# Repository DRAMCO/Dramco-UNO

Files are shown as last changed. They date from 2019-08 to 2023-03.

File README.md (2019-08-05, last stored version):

# Dramco UNO

LoRaWAN-enabled Arduino board developed by [DRAMCO](https://www.dramco.be) featuring an accelerometer and a onewire connection optimized for low-power.

## Folder Structure

```
├───app
│   ├───Accelero-Test
│   ├───Dramco-UNO
│   └───Temprature-Sensor-Test
├───hardware
└───libraries
    └───arduino-lmic-master
```

- Example applications can be found in `app`
- Hardware folder includes the schematics 
- Altered libraries can be found in the `libraries`folder

## Description

- The device sends temperature, accelerometer and the battery level each MEASURE_INTERVAL.
- The (onewire) temperature sensor needs to be connected to the TEMP_BUS pin
- The (I2C) accelerometer with id ACC_ID is accessed through the Wire.h library
- The battery level is measured through the readVcc() function
- The measurements sent by the node are formatted with the Cayenne Low Power Payload (https://github.com/myDevicesIoT/cayenne-docs/blob/master/docs/LORA.md)

##  Dependencies:
- OneWire lib
- DallasTemperature lib
- Install arduino-lmic-master in lib folder of the Arduino IDE (for windows this is most likely here: C:\Program Files (x86)\Arduino\libraries)
    * If you do not use the lib provided in this repo, be sure to uncomment '#define DISABLE_JOIN' in src>lmic>config.h
- DeepSleepScheduler lib

- LoRaWAN keys see: https://www.thethingsnetwork.org/docs/devices/registration.html

## How to cite
```LaTex
@Misc{Dramco-UNO,
  author =   {B. Thoen and G. Leenders},
  title =    {{Dramco UNO}},
  howpublished  = "\url{https://github.com/DRAMCO/Dramco-UNO}",
  doi = {10.5281/zenodo.2476999}
}
```

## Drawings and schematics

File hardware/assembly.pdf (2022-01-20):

## DRAMCO UNO

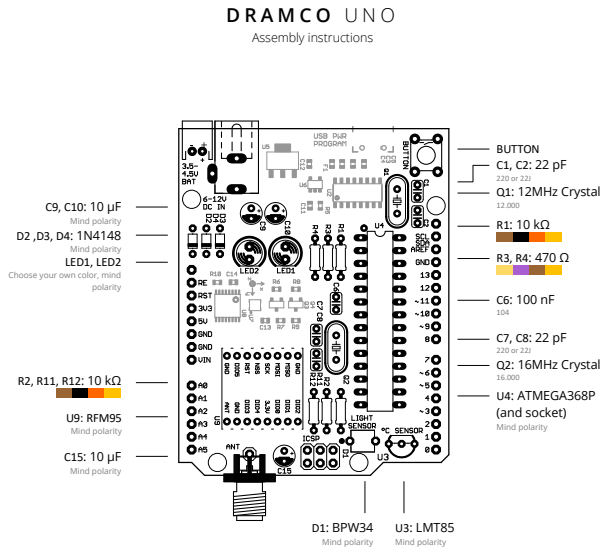
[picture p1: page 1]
Assembly instructions; BUTTON C1, C2: 22 pF 220 or 22J; Q1: 12MHz Crystal 12.000; U4: ATMEGA368P (and socket); Mind polarity; Mind polarity D2 ,D3, D4: 1N4148; Mind polarity LED1, LED2; polarity; Q2: 16MHz Crystal 16.000 R2, R11, R12: 10 kΩ; U3: LMT85; D1: BPW34; U9: RFM95 Mind polarity

Choose your own color, mind

## DRAMCO UNO

Bill of materials (and checklist)

¡ | R1, R2, R11, R12 | Resistors | 10 kΩ
¡ | R3, R4 | Resistors | 470 Ω
¡ | Q1 | Crystal oscillator | 12 MHz
¡ | Q2 | Cyrstal oscillator | 16 MHz
¡ | D1 | Light sensor diode BPW34
¡ | U9 | LoRa module | RFM95
¡ | D2, D3, D4 | Diodes | 1N4148
¡ | C1, C2, C7, C8 | Capacitors | 22 pF
¡ | C6 | Capacitor | 100 nF
¡ | C9, C10, C15 | Capacitors | 10 μF
¡ | LED1, LED2 | LED Diode | 5 mm (choose your own color)
¡ | U3 | Temperature sensor | LMT85
¡ | U4 | IC socket | 28 pin; for ATMEGA328P
¡ | BUTTON | Button | Push button
¡ | ANT | Antenna | Wire antenna 8.2 cm
0 | 1 | 2 | 3 | 4 | 5 | 6 | 7 | 8 | 9 | 10 | 11

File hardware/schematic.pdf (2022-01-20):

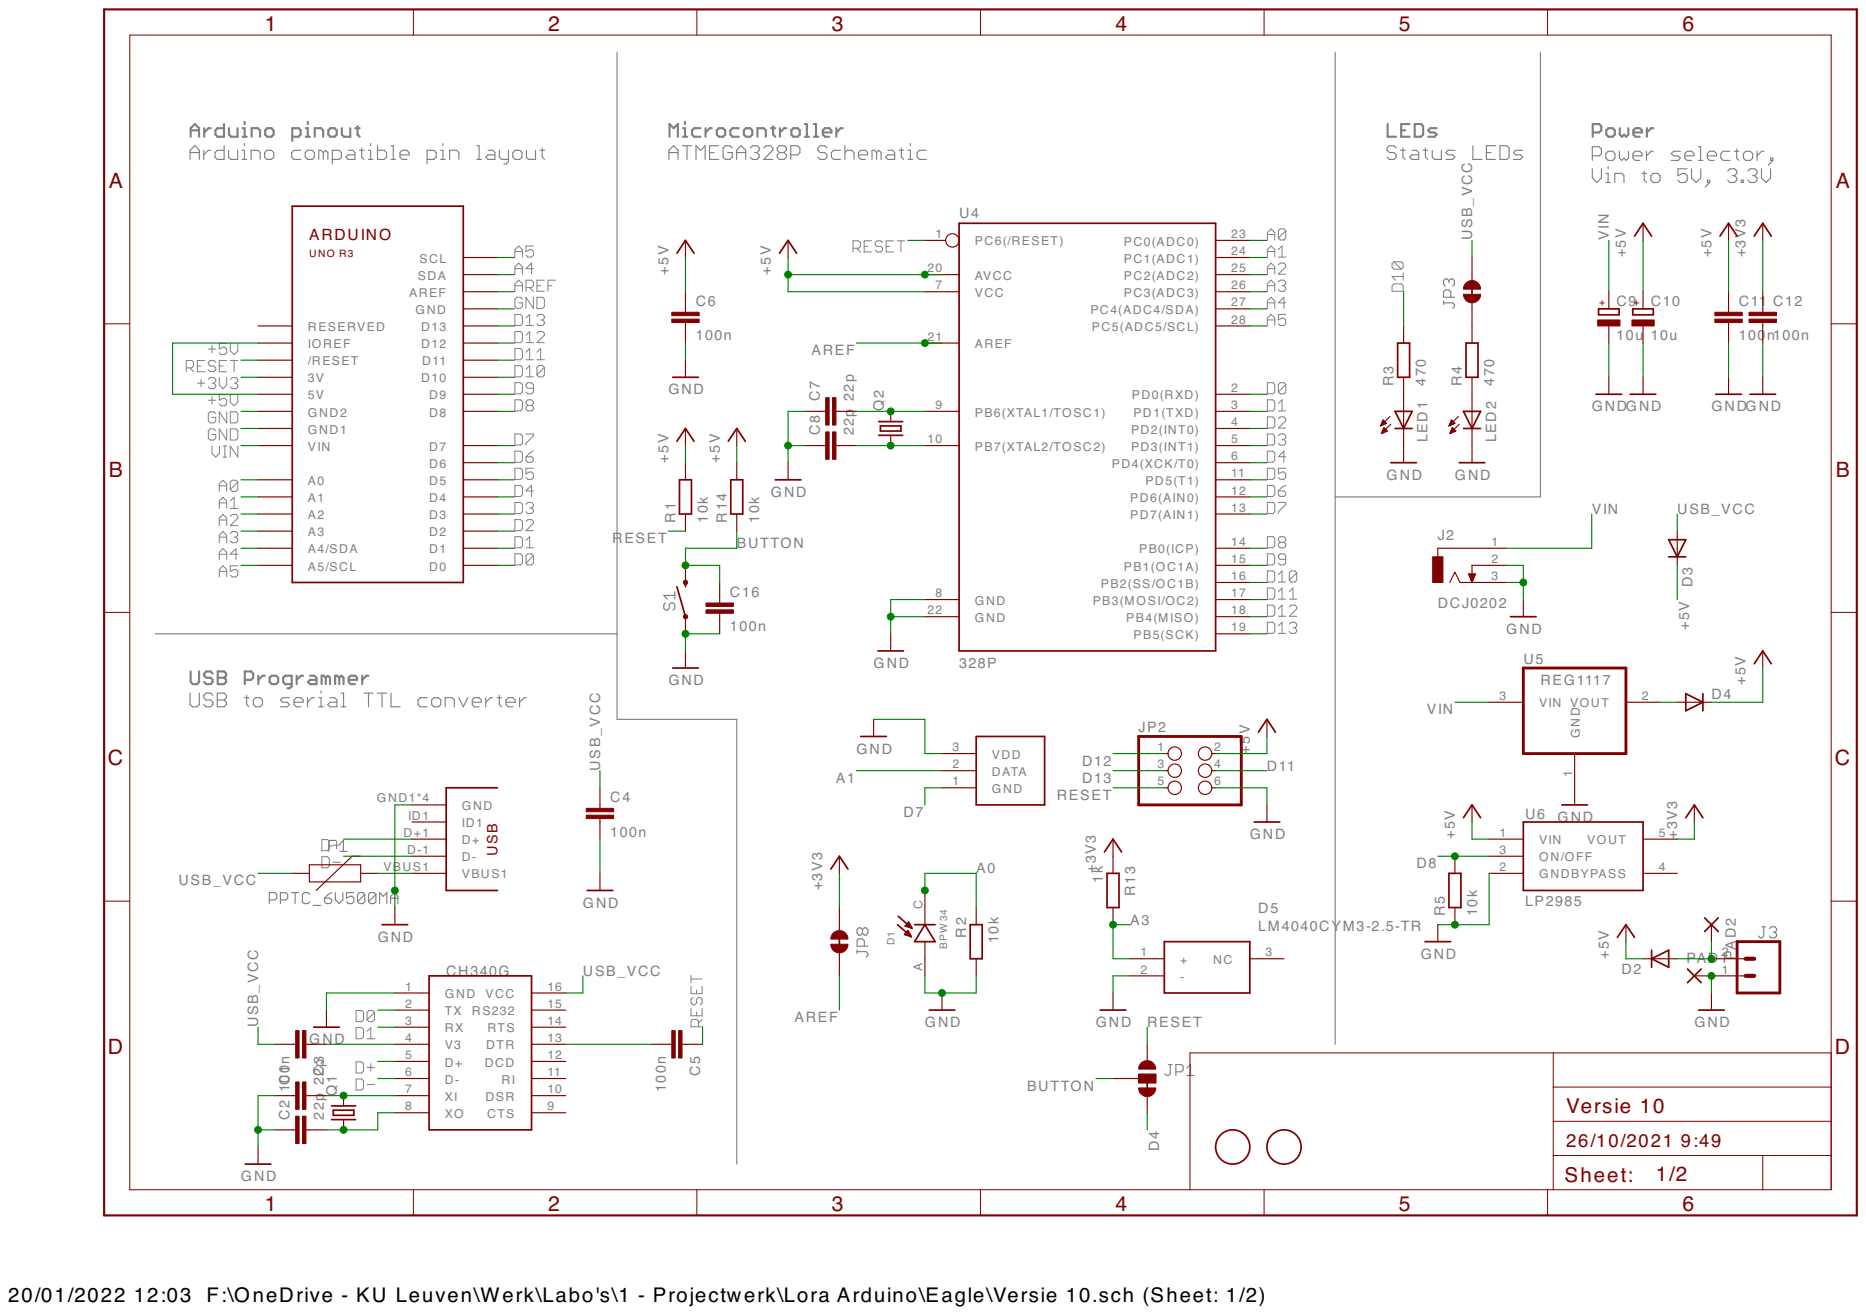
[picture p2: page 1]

20/01/2022 12:03 F:\OneDrive - KU Leuven\Werk\Labo's\1 - Projectwerk\Lora Arduino\Eagle\Versie 10.sch (Sheet: 1/2)

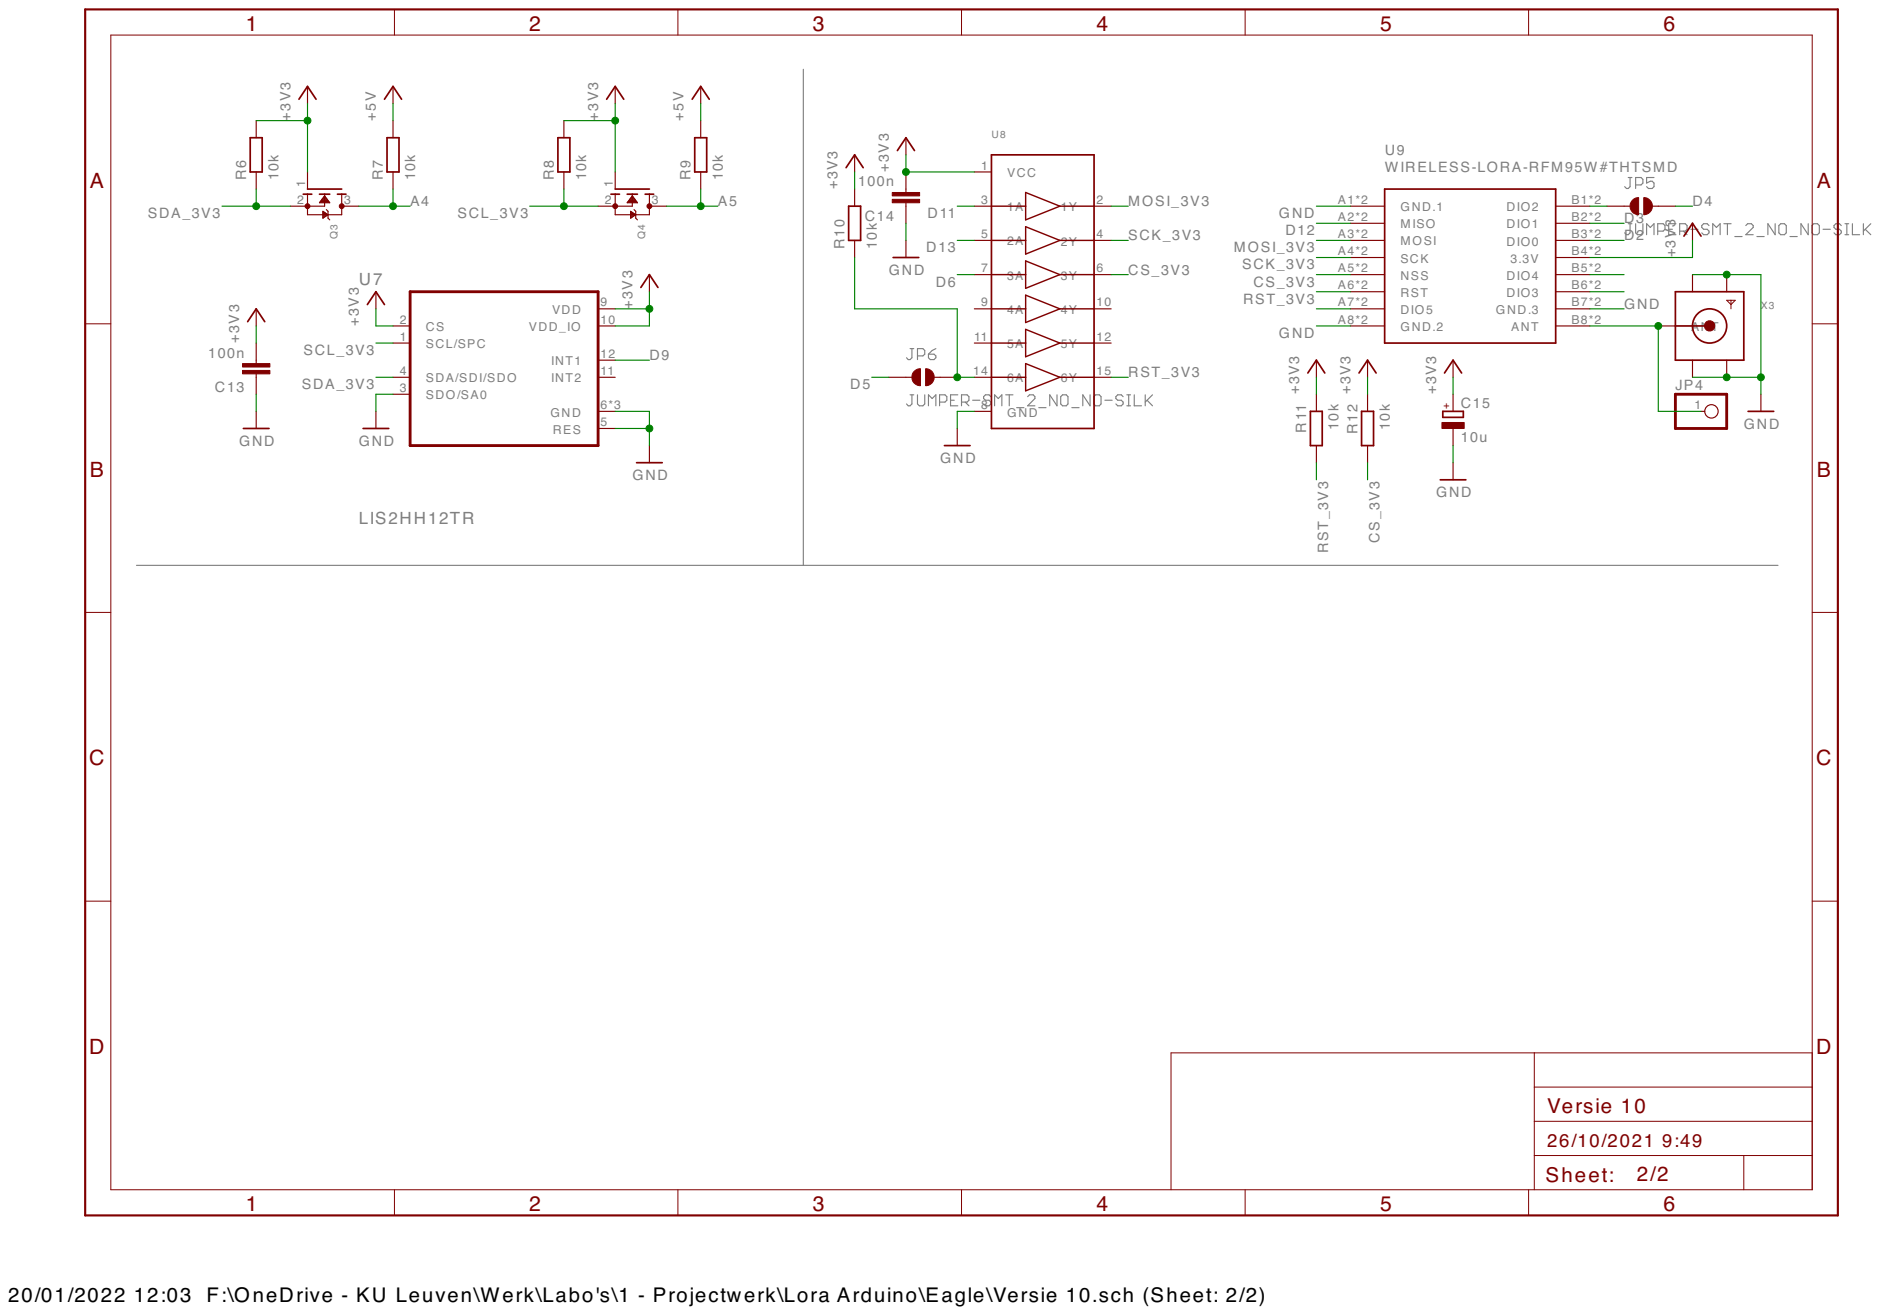
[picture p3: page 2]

20/01/2022 12:03 F:\OneDrive - KU Leuven\Werk\Labo's\1 - Projectwerk\Lora Arduino\Eagle\Versie 10.sch (Sheet: 2/2)

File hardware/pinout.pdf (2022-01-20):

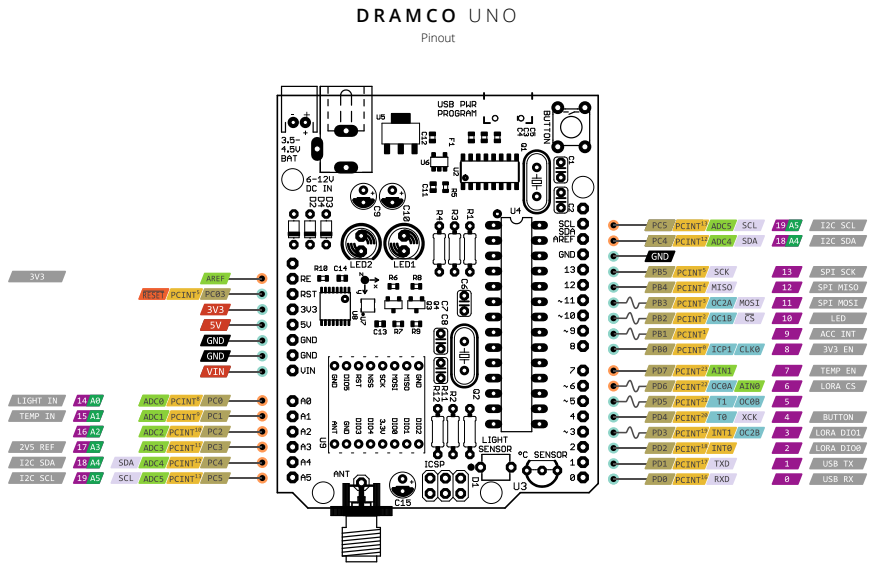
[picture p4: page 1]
Pinout

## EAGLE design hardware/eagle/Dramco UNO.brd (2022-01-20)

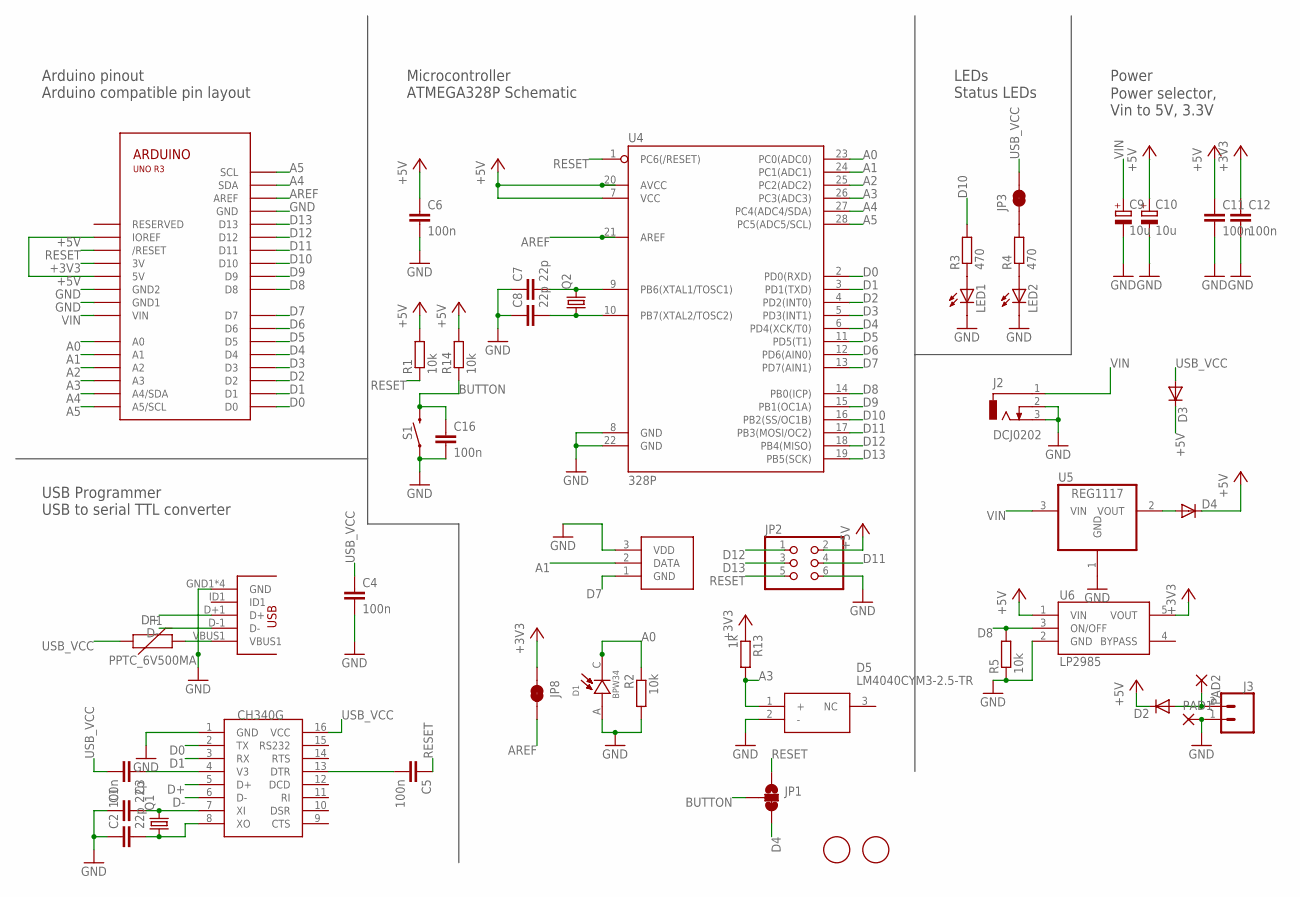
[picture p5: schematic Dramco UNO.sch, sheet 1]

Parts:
C1, C2, C7, C8: 22p; C025-024X044
C3, C4, C5, C11, C12, C16: 100n; C0603
C6: 100n; C025-024X044
C9, C10: 10u; E2-4
D1: BPW34; DIO_BPW34
D2, D3, D4: DIODE-D-5; D-5
D5: LM4040CYM3-2.5-TR; SOT95P235X111-3N
F1: PPTC_6V500MA; 0805
J1: USB-AB; USB-AB-MICRO-SMD_V02_BOSS
J2: DCJ0202
J3: CONN_02JST-PTH-2; JST-2-PTH
JP1: JUMPER-SMT_3_1-NC_TRACE_SILK; SMT-JUMPER_3_1-NC_TRACE_SILK
JP2: PINHD-2X3; 2X03
JP3, JP8: JUMPER-SMT_2_NC_TRACE_NO-SILK; SMT-JUMPER_2_NC_TRACE_NO-SILK
LED1, LED2: LED5MM
PAD1, PAD2: SMD2; SMD1,27-2,54
Q1, Q2: CRYSTALHC49S; HC49/S
R1, R2: 10k; 0204/7
R3, R4: 470; 0204/7
R5, R14: 10k; R0603
R13: 1k; R0603
S1: MOMENTARY-SWITCH-SPST-PTH-6.0MM; TACTILE_SWITCH_PTH_6.0MM
U1: ARDUINOR3-DIMENSION; ARDUINOR3
U2: CH340G; SOIC16
U3: DS18B20-TO92; TO92-
U4: 328P; DIP28
U5: REG1117; SOT223
U6: LP2985AIM5-3.3; SOT25
X1, X2: FIDUCIAL; FIDUCIAL_1MM

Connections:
+3V3: C12.1, JP8.1, R13.1, U1.3V, U6.5 (VOUT); also elsewhere on the board
+5V: C6.1, C10.+, C11.1, D2.C, D3.C, D4.C, JP2.2, R1.2, R14.2, U1.5V, U1.IOREF, U4.7 (VCC), U4.20 (AVCC), U6.1 (VIN); also elsewhere on the board
A0: D1.C, R2.1, U1.A0, U4.23 (PC0(ADC0))
A1: U1.A1, U3.2 (DATA), U4.24 (PC1(ADC1))
A2: U1.A2, U4.25 (PC2(ADC2))
A3: D5.1 (+), R13.2, U1.A3, U4.26 (PC3(ADC3))
A4: U1.A4 (A4/SDA), U1.SDA, U4.27 (PC4(ADC4/SDA)); also elsewhere on the board
A5: U1.A5 (A5/SCL), U1.SCL, U4.28 (PC5(ADC5/SCL)); also elsewhere on the board
AREF: JP8.2, U1.AREF, U4.21 (AREF)
BUTTON: C16.1, JP1.2, R14.1, S1.3 (2)
D0: U1.D0, U2.2 (TX), U4.2 (PD0(RXD))
D1: U1.D1, U2.3 (RX), U4.3 (PD1(TXD))
D2: U1.D2, U4.4 (PD2(INT0)); also elsewhere on the board
D3: U1.D3, U4.5 (PD3(INT1)); also elsewhere on the board
D4: JP1.3, U1.D4, U4.6 (PD4(XCK/T0)); also elsewhere on the board
D5: U1.D5, U4.11 (PD5(T1)); also elsewhere on the board
D6: U1.D6, U4.12 (PD6(AIN0)); also elsewhere on the board
D7: U1.D7, U3.1 (GND), U4.13 (PD7(AIN1))
D8: R5.2, U1.D8, U4.14 (PB0(ICP)), U6.3 (ON/OFF)
D9: U1.D9, U4.15 (PB1(OC1A)); also elsewhere on the board
D10: R3.2, U1.D10, U4.16 (PB2(SS/OC1B))
D11: JP2.4, U1.D11, U4.17 (PB3(MOSI/OC2)); also elsewhere on the board
D12: JP2.1, U1.D12, U4.18 (PB4(MISO)); also elsewhere on the board
D13: JP2.3, U1.D13, U4.19 (PB5(SCK)); also elsewhere on the board
D+: J1.D+1 (D+), U2.5 (D+)
D-: J1.D-1 (D-), U2.6 (D-)
GND: C1.1, C2.1, C4.2, C6.2, C7.1, C8.1, C9.-, C10.-, C11.2, C12.2, C16.2, D1.A, D5.2 (-), J1.GND1 (GND), J1.P$1 (GND), J1.P$2 (GND), J1.P$3 (GND), J2.2, J2.3, J3.1, JP2.6, LED1.K (C), LED2.K (C), PAD1.1, R2.2, R5.1, S1.1, U1.GND, U1.GND1, U1.GND2, U2.1 (GND), U3.3 (VDD), U4.8 (GND), U4.22 (GND), U5.1 (GND), U6.2 (GND); also elsewhere on the board
unnamed: C7.2, Q2.2, U4.9 (PB6(XTAL1/TOSC1))
unnamed: C8.2, Q2.1, U4.10 (PB7(XTAL2/TOSC2))
unnamed: C1.2, Q1.2, U2.7 (XI)
unnamed: C2.2, Q1.1, U2.8 (XO)
unnamed: C3.1, U2.4 (V3)
unnamed: LED1.A, R3.1
unnamed: LED2.A, R4.1
unnamed: C5.2, U2.13 (DTR)
unnamed: D4.A, U5.2 (VOUT)
unnamed: F1.2, J1.VBUS1
unnamed: JP3.1, R4.2
RESET: C5.1, JP1.1, JP2.5, R1.1, U1.RESET (/RESET), U4.1 (PC6(/RESET))
USB_VCC: C3.2, C4.1, D3.A, F1.1, JP3.2, U2.16 (VCC)
VBAT: D2.A, J3.2, PAD2.1
VIN: C9.+, J2.1, U1.VIN, U5.3 (VIN)

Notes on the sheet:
Arduino pinout
Arduino compatible pin layout
Microcontroller
ATMEGA328P Schematic
USB Programmer
USB to serial TTL converter
LEDs
Status LEDs
Power
Power selector, Vin to 5V, 3.3V

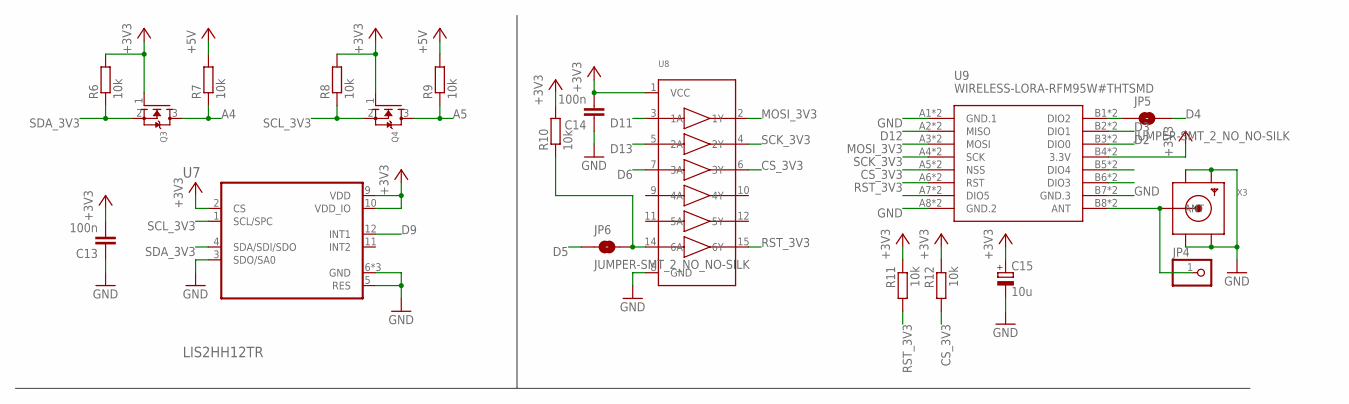
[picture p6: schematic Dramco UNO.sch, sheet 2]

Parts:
C13, C14: 100n; C0603
C15: 10u; E2-4
JP4: PINHD-1X1; 1X01
JP5, JP6: JUMPER-SMT_2_NO_NO-SILK; SMT-JUMPER_2_NO_NO-SILK
Q3, Q4: MOSFET-NREFLOW; SOT23
R6, R7, R8, R9, R10: 10k; R0603
R11, R12: 10k; 0204/7
U7: LIS2HH12TR; PQFN50P200X200X100-12N
U8: 74HC4050DTSSOP; TSSOP16
U9: WIRELESS-LORA-RFM95W#THTSMD
X3: SMACONNECTOR_EDGE_UFL; SMA_EDGELAUNCH_UFL

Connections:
+3V3: C13.2, C14.2, C15.+, Q3.1 (G), Q4.1 (G), R6.2, R8.2, R10.2, R11.1, R12.1, U7.2 (CS), U7.9 (VDD), U7.10 (VDD_IO), U8.1 (VCC), U9.B4 (3.3V), U9.B12 (3.3V); also elsewhere on the board
+5V: R7.2, R9.2; also elsewhere on the board
A4: Q3.3 (D), R7.1; also elsewhere on the board
A5: Q4.3 (D), R9.1; also elsewhere on the board
CS_3V3: R12.2, U8.6 (3Y), U9.A5 (NSS), U9.A13 (NSS)
D2: U9.B3 (DIO0), U9.B11 (DIO0); also elsewhere on the board
D3: U9.B2 (DIO1), U9.B10 (DIO1); also elsewhere on the board
D4: JP5.2; also elsewhere on the board
D5: JP6.1; also elsewhere on the board
D6: U8.7 (3A); also elsewhere on the board
D9: U7.12 (INT1); also elsewhere on the board
D11: U8.3 (1A); also elsewhere on the board
D12: U9.A2 (MISO), U9.A10 (MISO); also elsewhere on the board
D13: U8.5 (2A); also elsewhere on the board
GND: C13.1, C14.1, C15.-, U7.3 (SDO/SA0), U7.5 (RES), U7.6 (GND), U7.7 (GND), U7.8 (GND), U8.8 (GND), U9.A1 (GND.1), U9.A8 (GND.2), U9.A9 (GND.1), U9.A16 (GND.2), U9.B7 (GND.3), U9.B15 (GND.3), X3.GND@1 (GND1), X3.GND@2 (GND2), X3.GND@3 (GND3), X3.GND@4 (GND4); also elsewhere on the board
MOSI_3V3: U8.2 (1Y), U9.A3 (MOSI), U9.A11 (MOSI)
unnamed: JP4.1, U9.B8 (ANT), U9.B16 (ANT), X3.P (ANT)
unnamed: JP5.1, U9.B1 (DIO2), U9.B9 (DIO2)
unnamed: JP6.2, R10.1, U8.14 (6A)
unnamed: U9.A7 (DIO5), U9.A15 (DIO5)
unnamed: U9.B5 (DIO4), U9.B13 (DIO4)
unnamed: U9.B6 (DIO3), U9.B14 (DIO3)
RST_3V3: R11.2, U8.15 (6Y), U9.A6 (RST), U9.A14 (RST)
SCK_3V3: U8.4 (2Y), U9.A4 (SCK), U9.A12 (SCK)
SCL_3V3: Q4.2 (S), R8.1, U7.1 (SCL/SPC)
SDA_3V3: Q3.2 (S), R6.1, U7.4 (SDA/SDI/SDO)

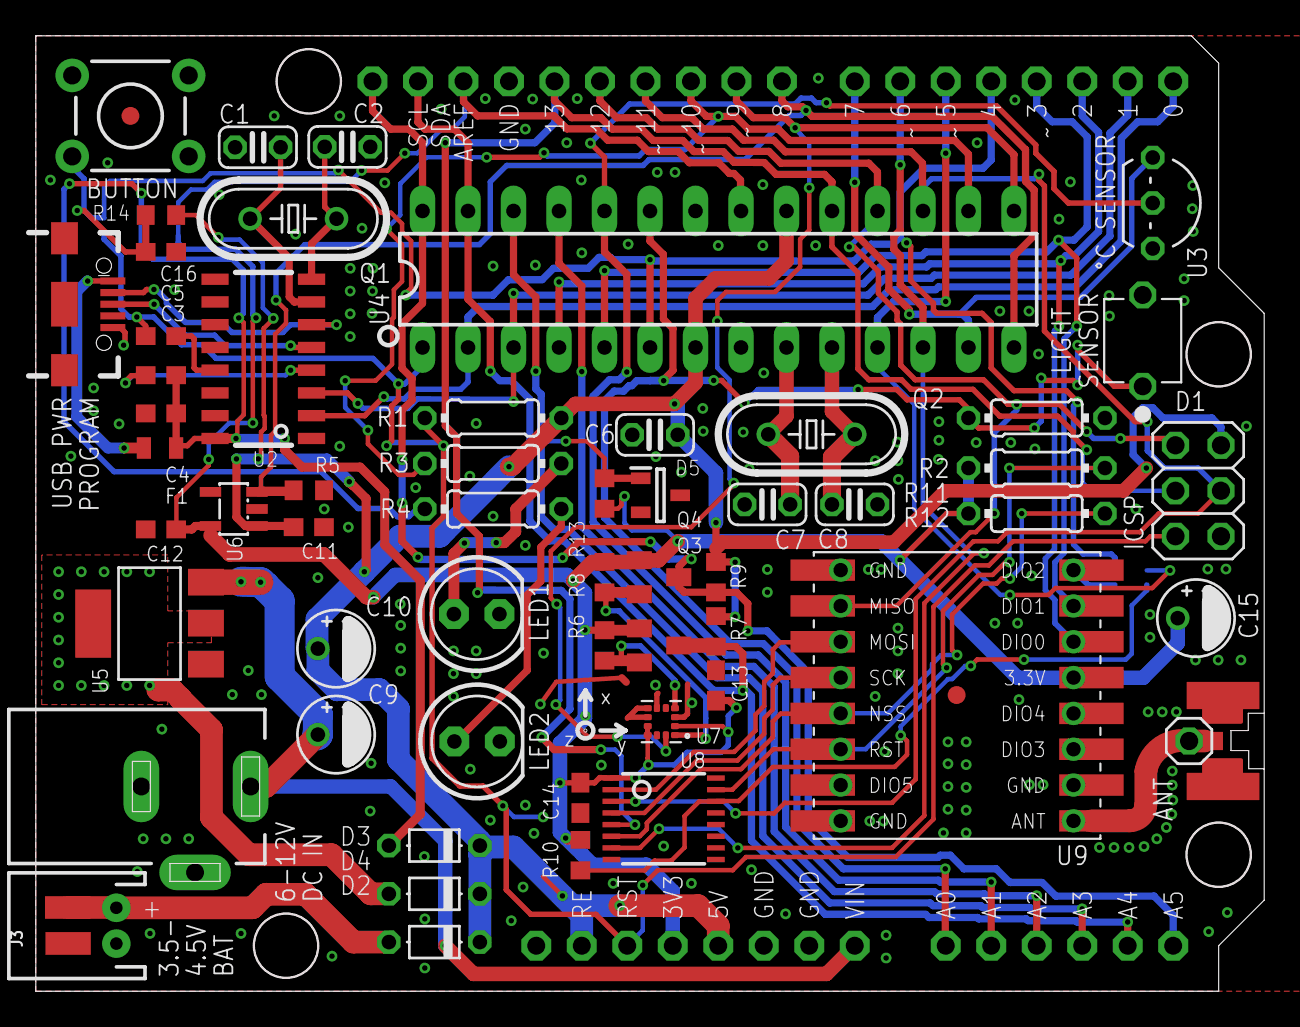
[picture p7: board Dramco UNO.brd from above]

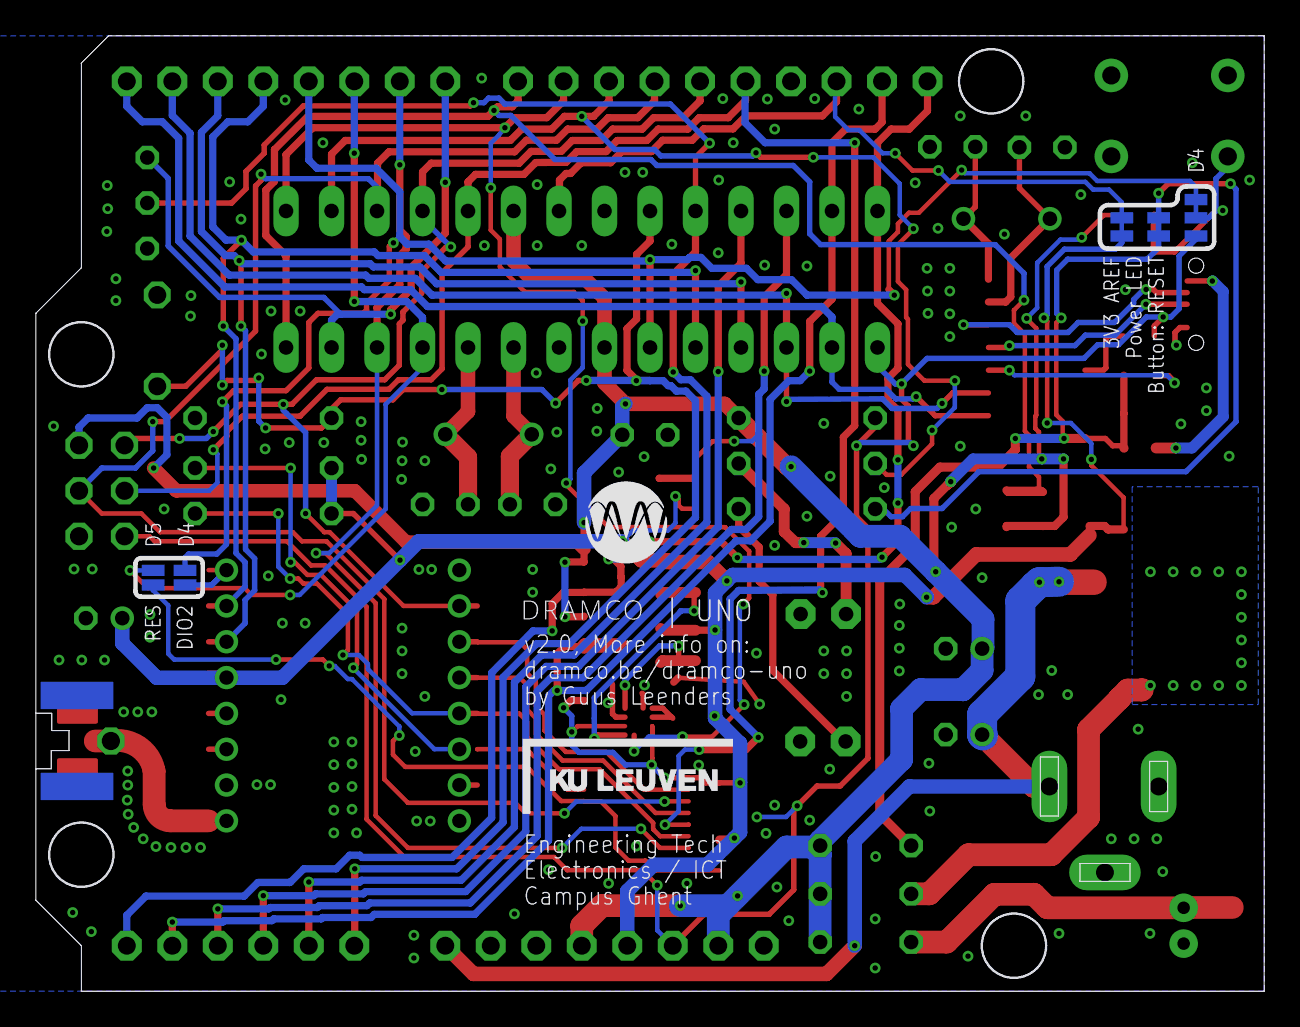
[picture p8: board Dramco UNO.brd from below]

Board: 2 copper layers, 68.6 x 53.3 mm, 67 parts (5 on the bottom side), 54 nets.

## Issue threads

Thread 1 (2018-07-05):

Wire.requestFrom() should not be followed by Wire.endTransmission().

Koepel, 2018-07-05:
In the files:
- Dramco-UNO/Dramco-UNO/Dramco-UNO.ino
- Dramco-UNO/Accelero-Test/Accelero-Test.ino

the Wire.requestFrom() is followed by a Wire.endTransmission(). That Wire.endTransmission() at the end of the function can be removed. Also a Wire.beginTransmission() should not be used before a Wire.requestFrom().
Explanation: [Common-mistakes](https://github.com/Koepel/How-to-use-the-Arduino-Wire-library/wiki/Common-mistakes), number 2 and 3.

GillesC, 2018-11-16:
@BartThoen

If I am correct, we should remove these lines:

https://github.com/DRAMCO/Dramco-UNO/blob/154ab29cc6e2b9cfb34cef466507e962b0f7328a/Dramco-UNO/Dramco-UNO.ino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

https://github.com/DRAMCO/Dramco-UNO/blob/154ab29cc6e2b9cfb34cef466507e962b0f7328a/Dramco-UNO/Dramco-UNO.ino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

Koepel, 2018-11-16:
Yes, those lines in "Dramco-UNO.ino".

In "Accelero-Test.ino" it is line [104](https://github.com/DRAMCO/Dramco-UNO/blob/master/Accelero-Test/Accelero-Test.ino#L104) and [113](https://github.com/DRAMCO/Dramco-UNO/blob/master/Accelero-Test/Accelero-Test.ino#L113) at the moment.

GillesC, 2018-11-17:
@Koepel , thank you for the contribution!

Closed 2020-10-01.

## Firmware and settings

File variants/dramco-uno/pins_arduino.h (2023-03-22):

/*
  pins_arduino.h - Pin definition functions for Arduino
  Part of Arduino - http://www.arduino.cc/

  Copyright (c) 2007 David A. Mellis

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
  You should have received a copy of the GNU Lesser General
  Public License along with this library; if not, write to the
  Free Software Foundation, Inc., 59 Temple Place, Suite 330,
  Boston, MA  02111-1307  USA
*/

#ifndef Pins_Arduino_h
#define Pins_Arduino_h

#include <avr/pgmspace.h>

#define NUM_DIGITAL_PINS            20
#define NUM_ANALOG_INPUTS           6
#define analogInputToDigitalPin(p)  ((p < 6) ? (p) + 14 : -1)

#if defined(__AVR_ATmega8__)
#define digitalPinHasPWM(p)         ((p) == 9 || (p) == 10 || (p) == 11)
#else
#define digitalPinHasPWM(p)         ((p) == 3 || (p) == 5 || (p) == 6 || (p) == 9 || (p) == 10 || (p) == 11)
#endif

#define PIN_SPI_SS    (10)
#define PIN_SPI_MOSI  (11)
#define PIN_SPI_MISO  (12)
#define PIN_SPI_SCK   (13)

static const uint8_t SS   = PIN_SPI_SS;
static const uint8_t MOSI = PIN_SPI_MOSI;
static const uint8_t MISO = PIN_SPI_MISO;
static const uint8_t SCK  = PIN_SPI_SCK;

#define PIN_WIRE_SDA        (18)
#define PIN_WIRE_SCL        (19)

static const uint8_t SDA = PIN_WIRE_SDA;
static const uint8_t SCL = PIN_WIRE_SCL;

#if HARDWARE_VERSION >= 2
#define LED_BUILTIN 10
#else
#define LED_BUILTIN 4
#endif

#define PIN_A0   (14)
#define PIN_A1   (15)
#define PIN_A2   (16)
#define PIN_A3   (17)
#define PIN_A4   (18)
#define PIN_A5   (19)
#define PIN_A6   (20)
#define PIN_A7   (21)

static const uint8_t A0 = PIN_A0;
static const uint8_t A1 = PIN_A1;
static const uint8_t A2 = PIN_A2;
static const uint8_t A3 = PIN_A3;
static const uint8_t A4 = PIN_A4;
static const uint8_t A5 = PIN_A5;
static const uint8_t A6 = PIN_A6;
static const uint8_t A7 = PIN_A7;

#define digitalPinToPCICR(p)    (((p) >= 0 && (p) <= 21) ? (&PCICR) : ((uint8_t *)0))
#define digitalPinToPCICRbit(p) (((p) <= 7) ? 2 : (((p) <= 13) ? 0 : 1))
#define digitalPinToPCMSK(p)    (((p) <= 7) ? (&PCMSK2) : (((p) <= 13) ? (&PCMSK0) : (((p) <= 21) ? (&PCMSK1) : ((uint8_t *)0))))
#define digitalPinToPCMSKbit(p) (((p) <= 7) ? (p) : (((p) <= 13) ? ((p) - 8) : ((p) - 14)))

#define digitalPinToInterrupt(p)  ((p) == 2 ? 0 : ((p) == 3 ? 1 : NOT_AN_INTERRUPT))

#ifdef ARDUINO_MAIN

// On the Arduino board, digital pins are also used
// for the analog output (software PWM).  Analog input
// pins are a separate set.

// ATMEL ATMEGA8 & 168 / ARDUINO
//
//                  +-\/-+
//            PC6  1|    |28  PC5 (AI 5)
//      (D 0) PD0  2|    |27  PC4 (AI 4)
//      (D 1) PD1  3|    |26  PC3 (AI 3)
//      (D 2) PD2  4|    |25  PC2 (AI 2)
// PWM+ (D 3) PD3  5|    |24  PC1 (AI 1)
//      (D 4) PD4  6|    |23  PC0 (AI 0)
//            VCC  7|    |22  GND
//            GND  8|    |21  AREF
//            PB6  9|    |20  AVCC
//            PB7 10|    |19  PB5 (D 13)
// PWM+ (D 5) PD5 11|    |18  PB4 (D 12)
// PWM+ (D 6) PD6 12|    |17  PB3 (D 11) PWM
//      (D 7) PD7 13|    |16  PB2 (D 10) PWM
//      (D 8) PB0 14|    |15  PB1 (D 9) PWM
//                  +----+
//
// (PWM+ indicates the additional PWM pins on the ATmega168.)

// ATMEL ATMEGA1280 / ARDUINO
//
// 0-7 PE0-PE7   works
// 8-13 PB0-PB5  works
// 14-21 PA0-PA7 works 
// 22-29 PH0-PH7 works
// 30-35 PG5-PG0 works
// 36-43 PC7-PC0 works
// 44-51 PJ7-PJ0 works
// 52-59 PL7-PL0 works
// 60-67 PD7-PD0 works
// A0-A7 PF0-PF7
// A8-A15 PK0-PK7


// these arrays map port names (e.g. port B) to the
// appropriate addresses for various functions (e.g. reading
// and writing)
const uint16_t PROGMEM port_to_mode_PGM[] = {
	NOT_A_PORT,
	NOT_A_PORT,
	(uint16_t) &DDRB,
	(uint16_t) &DDRC,
	(uint16_t) &DDRD,
};

const uint16_t PROGMEM port_to_output_PGM[] = {
	NOT_A_PORT,
	NOT_A_PORT,
	(uint16_t) &PORTB,
	(uint16_t) &PORTC,
	(uint16_t) &PORTD,
};

const uint16_t PROGMEM port_to_input_PGM[] = {
	NOT_A_PORT,
	NOT_A_PORT,
	(uint16_t) &PINB,
	(uint16_t) &PINC,
	(uint16_t) &PIND,
};

const uint8_t PROGMEM digital_pin_to_port_PGM[] = {
	PD, /* 0 */
	PD,
	PD,
	PD,
	PD,
	PD,
	PD,
	PD,
	PB, /* 8 */
	PB,
	PB,
	PB,
	PB,
	PB,
	PC, /* 14 */
	PC,
	PC,
	PC,
	PC,
	PC,
};

const uint8_t PROGMEM digital_pin_to_bit_mask_PGM[] = {
	_BV(0), /* 0, port D */
	_BV(1),
	_BV(2),
	_BV(3),
	_BV(4),
	_BV(5),
	_BV(6),
	_BV(7),
	_BV(0), /* 8, port B */
	_BV(1),
	_BV(2),
	_BV(3),
	_BV(4),
	_BV(5),
	_BV(0), /* 14, port C */
	_BV(1),
	_BV(2),
	_BV(3),
	_BV(4),
	_BV(5),
};
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

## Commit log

2018-07-04 low power
2018-07-06 dynamic temp sensors
2018-07-09 Add supply voltage measurement
2018-07-10 small changes
    [BatteryToPercent.xlsx]
2018-07-10 implementing device discovery
2018-08-07 adding temp sensor detection
2018-08-08 added sensor initphase
2018-08-09 added devices
2018-08-14 added device ids
2018-11-19 Added hardware files
    [Dramco UNO.brd, Dramco UNO.sch]
2020-09-25 Changed to board/avr structure
    [Dramco UNO.brd, Dramco UNO.sch]
2020-09-28 Update boards.txt
    suppress lmic project config
2020-09-29 Added temperature and light sensor
2020-09-29 Added lpp payload for temperature
2020-09-29 Changed build in led
2020-09-30 Lowered brownout detection
    Extended fuse changed from FD to FE
2020-09-30 Added temp sensor enable
2020-09-30 Added accelerometer placeholders
2020-10-01 Added license and accelerometer lib (not tested)
2020-10-02 Added LPP accelerometer, fixed error
2020-10-02 Fixed accelerometer issues
2020-10-07 Changed pin mapping
    DIO2, reset NC; Led to 4
    [pins_arduino.h]
2020-10-07 Accelerometer working, added temp calibration
2020-10-07 Added pin check in int
2020-10-08 Added button
2020-10-12 Added non blocking i2c, started soil sensor
2020-10-19 Added accelerometer error function
2020-10-19 Removed low-power bug when #define DEBUG
2020-10-23 Added acceleromter example
2020-11-03 Fixed temperature bug
2020-11-09 Improved stability of temperature sensor
2022-01-20 Changed LED_BUILTIN for v2 hardware
2022-01-20 Added hardware documentation
    [Dramco UNO.GBL, Dramco UNO.GBO, Dramco UNO.GBP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]
2023-03-08 Button compatibility with v1 version
2023-03-13 Light sensor compatibility with v1 version

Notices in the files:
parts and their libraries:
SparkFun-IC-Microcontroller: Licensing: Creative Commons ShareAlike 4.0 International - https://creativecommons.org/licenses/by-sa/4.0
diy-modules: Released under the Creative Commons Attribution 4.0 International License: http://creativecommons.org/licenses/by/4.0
